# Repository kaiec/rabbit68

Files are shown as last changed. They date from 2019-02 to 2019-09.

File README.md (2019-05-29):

# The Rabbit68 Keyboard

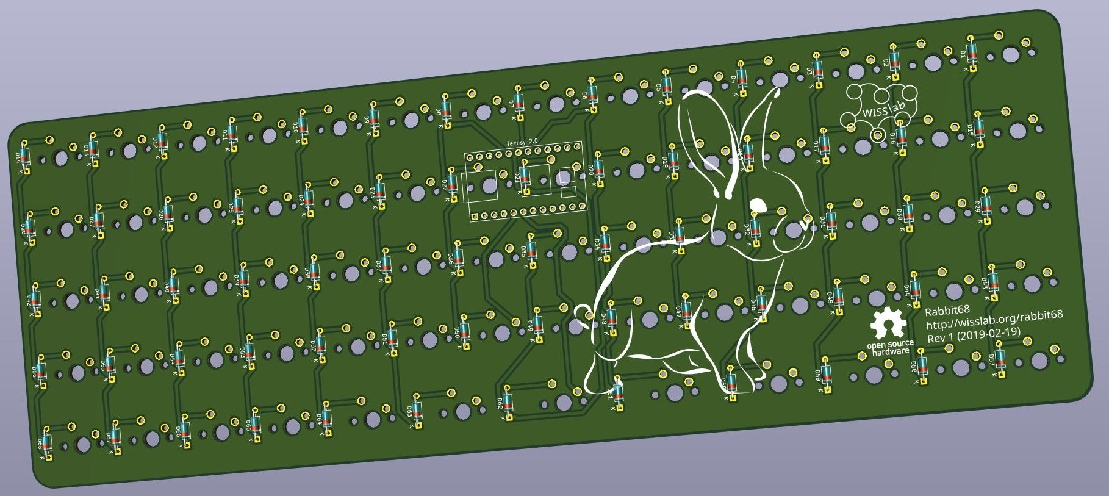
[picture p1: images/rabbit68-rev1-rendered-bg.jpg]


## Layout

http://www.keyboard-layout-editor.com/#/gists/c885816c6b763c657e40474b015e362b

## Design Principles

- Basis for experiments and customization at low cost.
- Ortholinear
- Only keys without stabilizers, i.e., 1.75 U maximum.
- Key sizes that are available in a standard (blank) qwerty keycaps set.
- No SMD

## Piggybacked Teensy 2.0

The PCB uses a Teensy 2.0 as controller. This way the whole PCB is basically just to avoid handwiring.

## Shopping List

This is what I use for the very first prototype. Neither fancy, nor quality, maybe not even good looking. We will see. Especially the switches seem way too cheap... but it should be good enough to test the overall layout and gain experiences with the design and build process.

- PCB: 
  - JLCPCB, about 20€ per 5 PCBs = 4€
- Controller
  - Teensy 2.0, eBay, 10€
- Diodes:
  - 1N4148, 500 pcs 3.38€ at Amazon = 1€
- Caps (ultra cheap standard sets, make sure all required sizes are contained): 
   - Schwarz blank PBT 61 ANSI Keybord Schlüsselkappen Set für MX Switches Mechanische Tastatur, eBay 12.62€
   - 104 Keycaps PBT Backlit Double-Shot für Mechanical Cherry MX Switch 10 Farben, eBay 9.91€
- Switches
  - MX Brown Switches, 10 pcs for 1.59€, eBay, 8 sets (to have some spares): 11.92€
- Case:
  - Some cheap wood, tbd
  - Some screws
  - Magnets (maybe, we'll see)

Sum: ~ 45 - 50 €

## Similar projects

### Shark PCB
- https://github.com/Gondolindrim/SharkPCB
- https://www.reddit.com/r/MechanicalKeyboards/comments/a2s485/sharkpcb_design_stream/

### DIY Low Profile Ortho
- https://easyeda.com/7zark7/Kailh-Ortholinear
- https://imgur.com/a/gqjEYFf
- https://www.reddit.com/r/MechanicalKeyboards/comments/8sy17h/diy_low_profile_ortho/

## Guides
- https://github.com/ruiqimao/keyboard-pcb-guide
- https://kbwiki.ai03.me/books/pcb-design

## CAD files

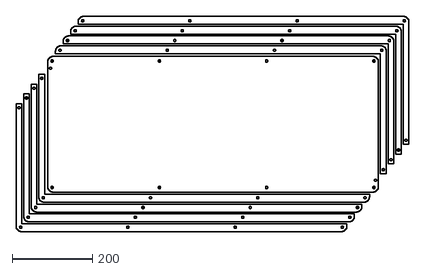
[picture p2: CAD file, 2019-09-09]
case/closedlayer-bottom-parts.dxf
978.5 x 536.1

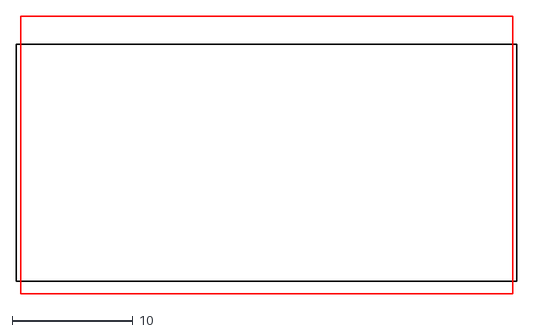
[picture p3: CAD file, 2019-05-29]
case/openlayer.dxf
41.5 x 23.0

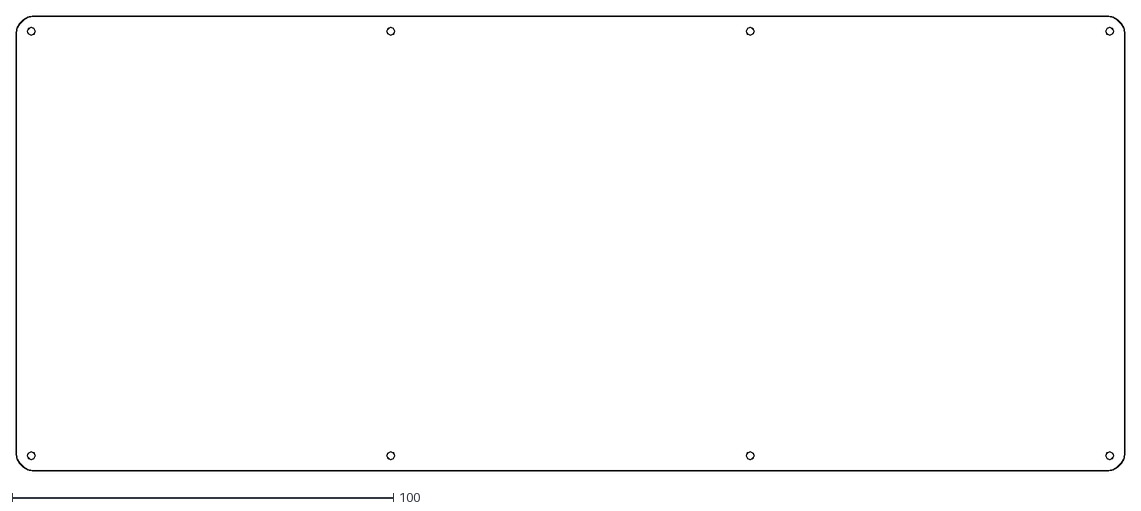
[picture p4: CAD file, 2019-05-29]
case/bottom.dxf
290.7 x 119.3

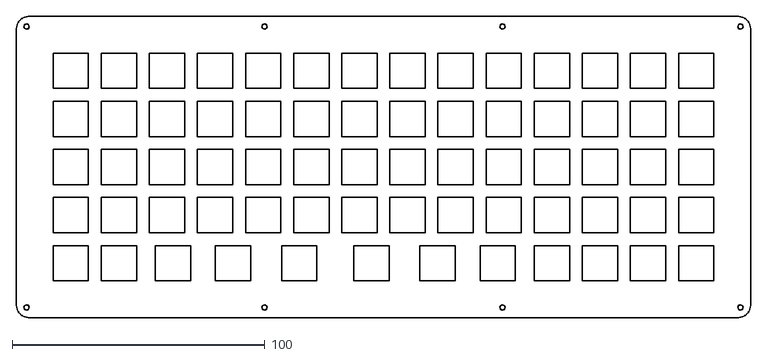
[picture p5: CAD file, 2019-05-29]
case/plate.dxf
290.7 x 119.3

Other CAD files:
case/closedlayer.dxf

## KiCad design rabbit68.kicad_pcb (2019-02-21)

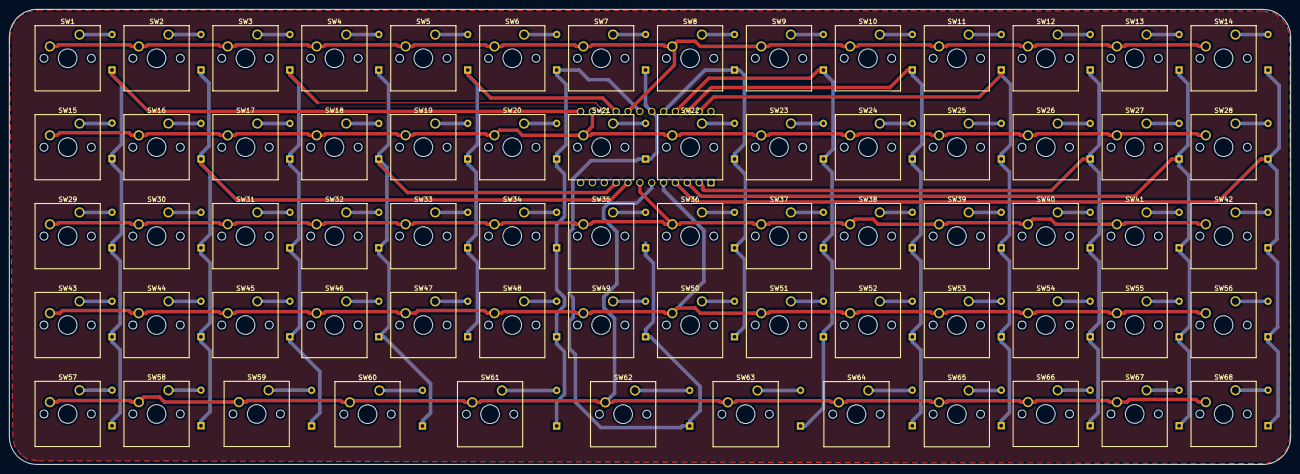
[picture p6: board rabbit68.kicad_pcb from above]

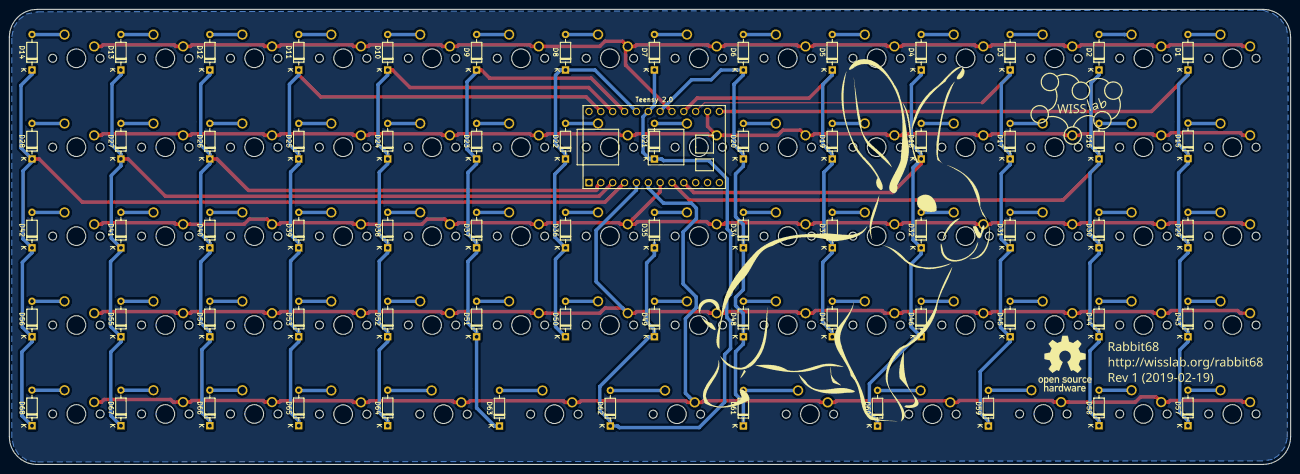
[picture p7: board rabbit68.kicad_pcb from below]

Board: 2 copper layers, 274.5 x 97.5 mm, 137 parts (69 on the bottom side), 87 nets.

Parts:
D1, D2, D3, D4, D5, D6, D7, D8, D9, D10, D11, D12, D13, D14, D15, D16, D17, D18, D19, D20, D21, D22, D23, D24, D25, D26, D27, D28, D29, D30, D31, D32, D33, D34, D35, D36, D37, D38, D39, D40, D41, D42, D43, D44, D45, D46, D47, D48, D49, D50, D51, D52, D53, D54, D55, D56, D57, D58, D59, D60, D61, D62, D63, D64, D65, D66, D67, D68: 1N4148; D_DO-35_SOD27_P7.62mm_Horizontal
SW1, SW2, SW3, SW4, SW5, SW6, SW7, SW8, SW9, SW10, SW11, SW12, SW13, SW14, SW15, SW16, SW17, SW18, SW19, SW20, SW21, SW22, SW23, SW24, SW25, SW26, SW27, SW28, SW29, SW30, SW31, SW32, SW33, SW34, SW35, SW36, SW37, SW38, SW39, SW40, SW41, SW42, SW43, SW44, SW45, SW46, SW47, SW48, SW49, SW50, SW51, SW52, SW53, SW54, SW55, SW56, SW57, SW58, SW65, SW66, SW67, SW68: SW_Push; SW_Cherry_MX1A_1.00u_PCB
SW59, SW60, SW63, SW64: SW_Push; SW_Cherry_MX1A_1.25u_PCB
SW61, SW62: SW_Push; SW_Cherry_MX1A_1.50u_PCB
Teensy 2.0: Teensy2.0-Teensy; Teensy2.0

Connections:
/COL1: D1.1, D15.1, D29.1, D43.1, D57.1, Teensy 2.0.18
/COL2: D2.1, D16.1, D30.1, D44.1, D58.1, Teensy 2.0.8
/COL3: D3.1, D17.1, D31.1, D45.1, D59.1, Teensy 2.0.20
/COL4: D4.1, D18.1, D32.1, D46.1, D60.1, Teensy 2.0.9
/COL5: D5.1, D19.1, D33.1, D47.1, Teensy 2.0.21
/COL6: D6.1, D20.1, D34.1, D48.1, D61.1, Teensy 2.0.23
/COL7: D7.1, D21.1, D35.1, D49.1, D62.1, Teensy 2.0.24
/COL8: D8.1, D22.1, D36.1, D50.1, Teensy 2.0.25
/COL9: D9.1, D23.1, D37.1, D51.1, D63.1, Teensy 2.0.26
/COL10: D10.1, D24.1, D38.1, D52.1, D64.1, Teensy 2.0.27
/COL11: D11.1, D25.1, D39.1, D53.1, D65.1, Teensy 2.0.28
/COL12: D12.1, D26.1, D40.1, D54.1, D66.1, Teensy 2.0.2
/COL13: D13.1, D27.1, D41.1, D55.1, D67.1, Teensy 2.0.3
/COL14: D14.1, D28.1, D42.1, D56.1, D68.1, Teensy 2.0.4
/ROW1: SW1.2, SW2.2, SW3.2, SW4.2, SW5.2, SW6.2, SW7.2, SW8.2, SW9.2, SW10.2, SW11.2, SW12.2, SW13.2, SW14.2, Teensy 2.0.22
/ROW2: SW15.2, SW16.2, SW17.2, SW18.2, SW19.2, SW20.2, SW21.2, SW22.2, SW23.2, SW24.2, SW25.2, SW26.2, SW27.2, SW28.2, Teensy 2.0.19
/ROW3: SW29.2, SW30.2, SW31.2, SW32.2, SW33.2, SW34.2, SW35.2, SW36.2, SW37.2, SW38.2, SW39.2, SW40.2, SW41.2, SW42.2, Teensy 2.0.7
/ROW4: SW43.2, SW44.2, SW45.2, SW46.2, SW47.2, SW48.2, SW49.2, SW50.2, SW51.2, SW52.2, SW53.2, SW54.2, SW55.2, SW56.2, Teensy 2.0.5
/ROW5: SW57.2, SW58.2, SW59.2, SW60.2, SW61.2, SW62.2, SW63.2, SW64.2, SW65.2, SW66.2, SW67.2, SW68.2, Teensy 2.0.6
unnamed: D1.2, SW1.1
unnamed: D2.2, SW2.1
unnamed: D3.2, SW3.1
unnamed: D4.2, SW4.1
unnamed: D5.2, SW5.1
unnamed: D6.2, SW6.1
unnamed: D7.2, SW7.1
unnamed: D8.2, SW8.1
unnamed: D9.2, SW9.1
unnamed: D10.2, SW10.1
unnamed: D11.2, SW11.1
unnamed: D12.2, SW12.1
unnamed: D13.2, SW13.1
unnamed: D14.2, SW14.1
unnamed: D15.2, SW15.1
unnamed: D16.2, SW16.1
unnamed: D17.2, SW17.1
unnamed: D18.2, SW18.1
unnamed: D19.2, SW19.1
unnamed: D20.2, SW20.1
unnamed: D21.2, SW21.1
unnamed: D22.2, SW22.1
unnamed: D23.2, SW23.1
unnamed: D24.2, SW24.1
unnamed: D25.2, SW25.1
unnamed: D26.2, SW26.1
unnamed: D27.2, SW27.1
unnamed: D28.2, SW28.1
unnamed: D29.2, SW29.1
unnamed: D30.2, SW30.1
unnamed: D31.2, SW31.1
unnamed: D32.2, SW32.1
unnamed: D33.2, SW33.1
unnamed: D34.2, SW34.1
unnamed: D35.2, SW35.1
unnamed: D36.2, SW36.1
unnamed: D37.2, SW37.1
unnamed: D38.2, SW38.1
unnamed: D39.2, SW39.1
unnamed: D40.2, SW40.1
unnamed: D41.2, SW41.1
unnamed: D42.2, SW42.1
unnamed: D43.2, SW43.1
unnamed: D44.2, SW44.1
unnamed: D45.2, SW45.1
unnamed: D46.2, SW46.1
unnamed: D47.2, SW47.1
unnamed: D48.2, SW48.1
unnamed: D49.2, SW49.1
unnamed: D50.2, SW50.1
unnamed: D51.2, SW51.1
unnamed: D52.2, SW52.1
unnamed: D53.2, SW53.1
unnamed: D54.2, SW54.1
unnamed: D55.2, SW55.1
unnamed: D56.2, SW56.1
unnamed: D57.2, SW57.1
unnamed: D58.2, SW58.1
unnamed: D59.2, SW59.1
unnamed: D60.2, SW60.1
unnamed: D61.2, SW61.1
unnamed: D62.2, SW62.1
unnamed: D63.2, SW63.1
unnamed: D64.2, SW64.1
unnamed: D65.2, SW65.1
unnamed: D66.2, SW66.1
unnamed: D67.2, SW67.1
unnamed: D68.2, SW68.1

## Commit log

2019-02-21 Revision 1, as ordered on 2019-02-20
    [rabbit68-B.Cu.gbr, rabbit68-B.Mask.gbr, rabbit68-B.Paste.gbr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]
2019-05-29 Case files
    [bottom.dxf, closedlayer.dxf, openlayer.dxf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]
2019-09-09 Space filling case parts
    [closedlayer-bottom-parts.dxf]
